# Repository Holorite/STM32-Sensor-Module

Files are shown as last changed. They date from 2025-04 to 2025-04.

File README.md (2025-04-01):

STM32U031C8T6 sensor module for CottonCandy.

**Debugger Digikey Part #**: 497-STLINK-V3MINIE-ND

Possible Improvements:
1. Use STM32L1 for extended preferred on JLCPCB (alternatives may be possible to reduce assembly cost)
2. Change stlink connector (2x7) to 7 (2x1) 1.27mm pitch headeres so they can be assembled by JLC (2x5 pin interface is also possible)
3. SMD stlink connectors are easier to use (but more expensive)
4. Replace CO2 with a more accurate sensor (SCD40, library very likely available), can remove other sensors too.
5. Change order of CC header pins to match 2.0 interface
6. Add LSE for accurate RTC or LPUART functionality
7. Remove some breakout pins and replace with ready I2C + power for sensor connections
8. Modify interface so module can connect vertically to CottonCandy
9. ADC not usable (with 1/3 bridge) when tested using dry ice (-80C?)

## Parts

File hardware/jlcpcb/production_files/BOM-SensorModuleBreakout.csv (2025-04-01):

Comment | Designator | Footprint | LCSC | Quantity
10n | C6 | C_0402_1005Metric | C15195 | 1
100n | C10,C11,C12,C2,C3,C4,C5,C9 | C_0402_1005Metric | C1525 | 8
4.7u | C1 | C_0603_1608Metric | C19666 | 1
STC31-C-R3 | U3 | XDCR_STC31-C-R3 | C22396918 | 1
LED | D1 | LED_0603_1608Metric | C2286 | 1
2M | R4 | R_0603_1608Metric | C22976 | 1
STM32U031C8Tx | U1 | LQFP-48_7x7mm_P0.5mm | C23172783 | 1
220r | R6 | R_0402_1005Metric | C25091 | 1
10k | R1,R2,R3 | R_0402_1005Metric | C25744 | 3
1M | R5 | R_0402_1005Metric | C26083 | 1
1u | C7,C8 | C_0402_1005Metric | C52923 | 2
SHT4x | U2 | Sensirion_DFN-4_1.5x1.5mm_P0.8mm_SHT4x_NoCentralPad | C7461861 | 1
MS5607-02BA | U5 | LGA-8_3x5mm_P1.25mm | C97627 | 1

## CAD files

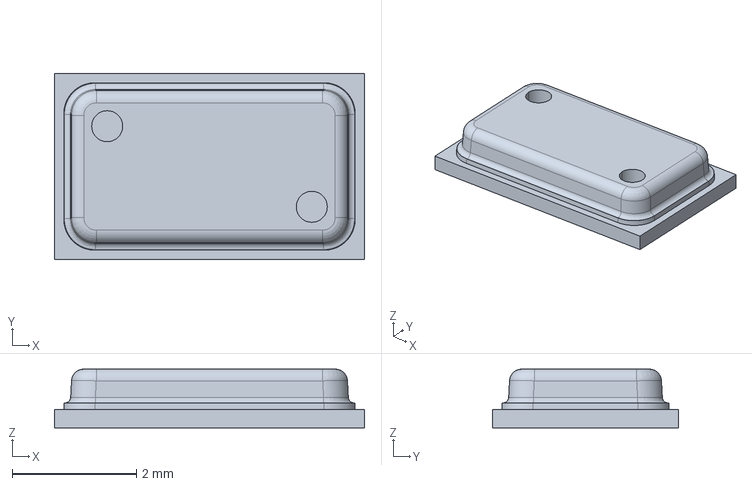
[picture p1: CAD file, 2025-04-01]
hardware/MS560702BA03_50/c-ms560702ba03-50-a-3d.stp
5.00 x 3.00 x 0.95 mm

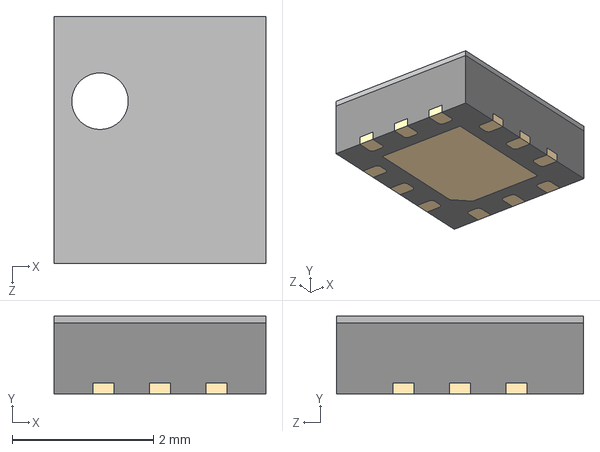
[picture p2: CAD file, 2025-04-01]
hardware/STC31_C_R3/STC31-C-R3.step
3.00 x 1.10 x 3.50 mm

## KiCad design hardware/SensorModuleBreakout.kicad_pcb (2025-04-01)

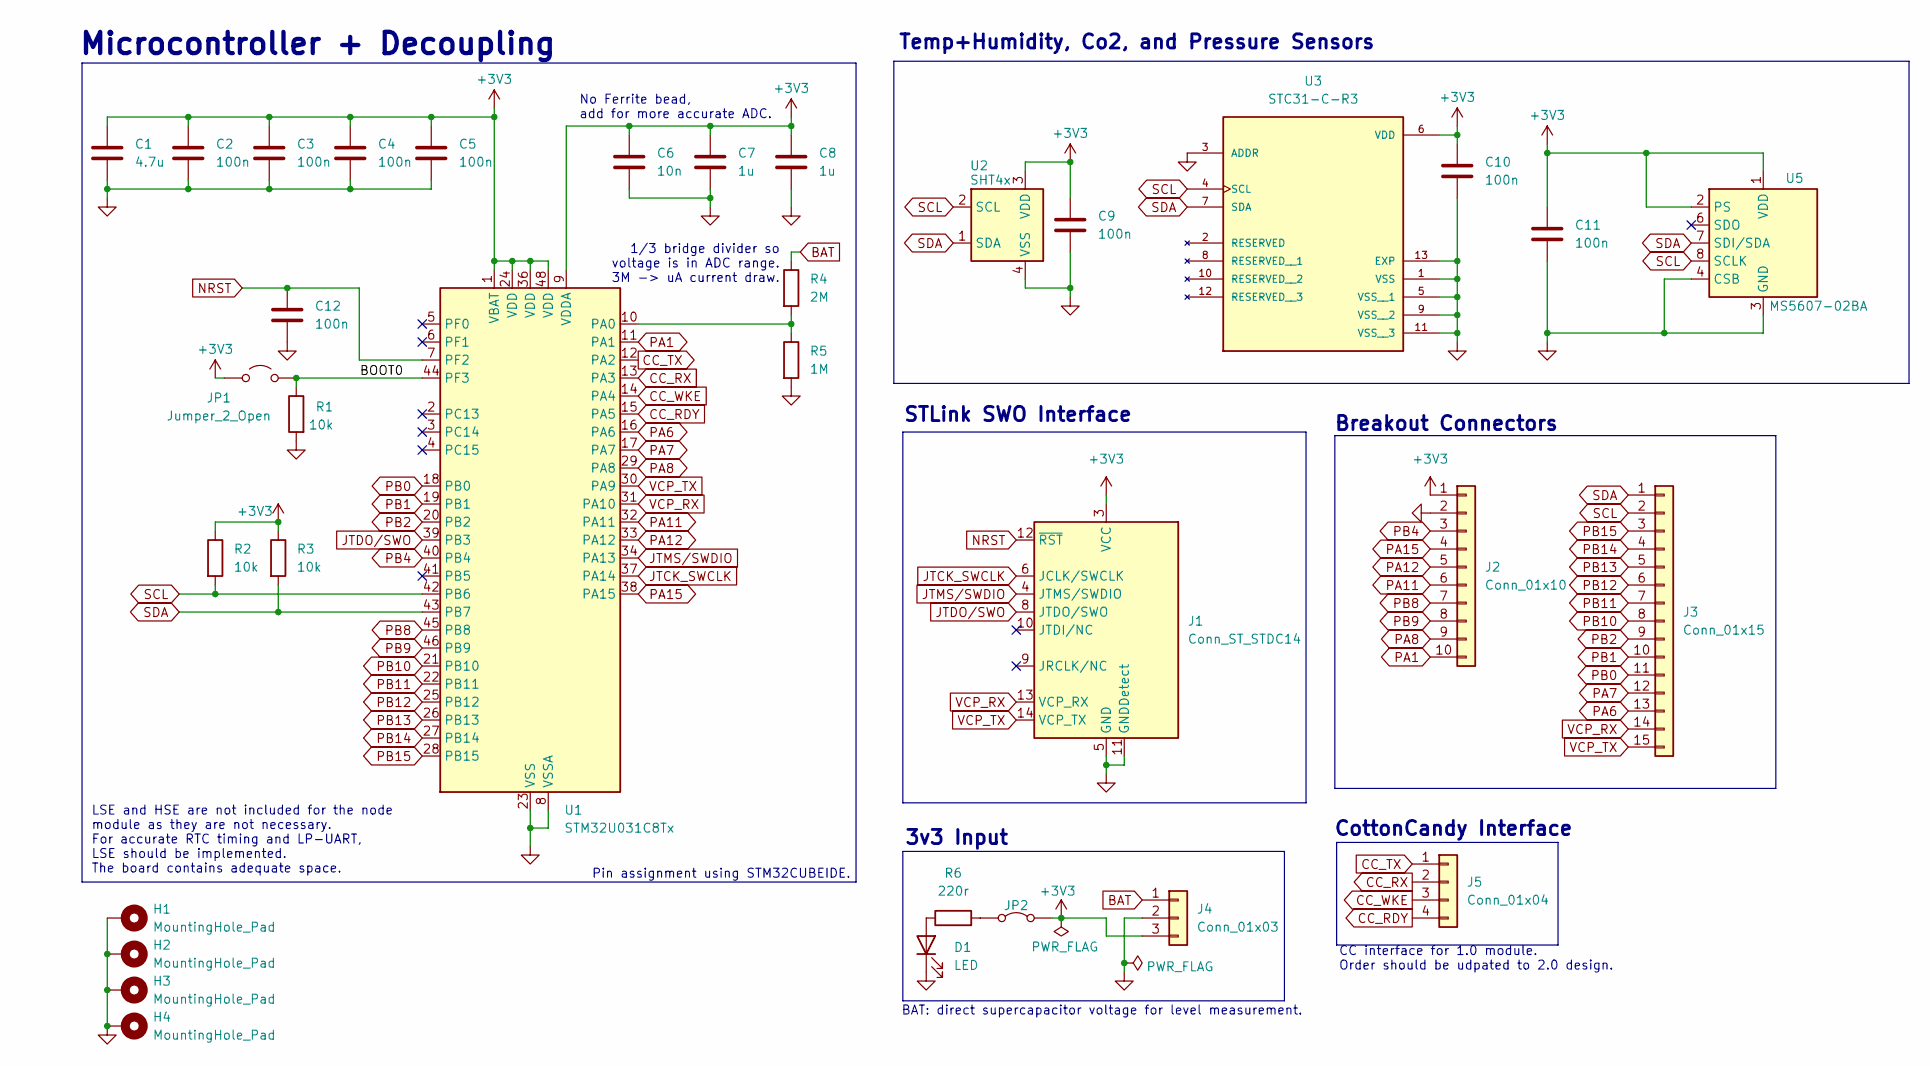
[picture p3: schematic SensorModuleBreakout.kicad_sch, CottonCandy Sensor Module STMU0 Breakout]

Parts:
C1: 4.7u; C_0603_1608Metric
C2, C3, C4, C5, C9, C10, C11, C12: 100n; C_0402_1005Metric
C6: 10n; C_0402_1005Metric
C7, C8: 1u; C_0402_1005Metric
D1: LED; LED_0603_1608Metric
H1, H2, H3, H4: MountingHole_Pad; MountingHole_3.2mm_M3_DIN965_Pad
J1: Conn_ST_STDC14; PinHeader_2x07_P1.27mm_Vertical
J2: Conn_01x10; PinHeader_1x10_P2.54mm_Vertical
J3: Conn_01x15; PinHeader_1x15_P2.54mm_Vertical
J4: Conn_01x03; JST_XH_B3B-XH-A_1x03_P2.50mm_Vertical
J5: Conn_01x04; JST_XH_B4B-XH-A_1x04_P2.50mm_Vertical
JP1: Jumper_2_Open; TestPoint_2Pads_Pitch2.54mm_Drill0.8mm
JP2: JP; TestPoint_2Pads_Pitch2.54mm_Drill0.8mm
R1, R2, R3: 10k; R_0402_1005Metric
R4: 2M; R_0603_1608Metric
R5: 1M; R_0402_1005Metric
R6: 220r; R_0402_1005Metric
U1: STM32U031C8Tx; LQFP-48_7x7mm_P0.5mm
U2: SHT4x; Sensirion_DFN-4_1.5x1.5mm_P0.8mm_SHT4x_NoCentralPad
U3: STC31-C-R3; XDCR_STC31-C-R3; PARTREV 3.2
U5: MS5607-02BA; LGA-8_3x5mm_P1.25mm

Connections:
+3V3: C1.1, C2.1, C3.1, C4.1, C5.1, C6.1, C7.1, C8.1, C9.1, C10.1, C11.1, J1.3 (VCC), J2.1, J4.3, JP1.1 (A), JP2.2 (B), R2.1, R3.1, U1.1 (VBAT), U1.9 (VDDA), U1.24 (VDD), U1.36 (VDD), U1.48 (VDD), U2.3 (VDD), U3.6 (VDD), U5.1 (VDD), U5.2 (PS); also elsewhere on the board
/BOOT0: JP1.2 (B), R1.1, U1.44 (PF3)
CC_RDY: J5.4, U1.15 (PA5)
CC_RX: J5.2, U1.13 (PA3)
CC_TX: J5.1, U1.12 (PA2)
CC_WKE: J5.3, U1.14 (PA4)
GND: C1.2, C2.2, C3.2, C4.2, C5.2, C6.2, C7.2, C8.2, C9.2, C10.2, C11.2, C12.2, D1.1 (K), H1.1, H2.1, H3.1, H4.1, J1.5 (GND), J1.7 (GND), J1.11 (GNDDetect), J2.2, J4.2, R1.2, R5.2, U1.8 (VSSA), U1.23 (VSS), U1.35 (VSS), U1.47 (VSS), U2.4 (VSS), U3.1 (VSS), U3.3 (ADDR), U3.5 (VSS__1), U3.9 (VSS__2), U3.11 (VSS__3), U3.13 (EXP), U5.3 (GND), U5.4 (CSB), U5.5 (CSB); also elsewhere on the board
JTCK_SWCLK: J1.6 (JCLK/SWCLK), U1.37 (PA14); also elsewhere on the board
JTDO/SWO: J1.8 (JTDO/SWO), U1.39 (PB3); also elsewhere on the board
JTMS/SWDIO: J1.4 (JTMS/SWDIO), U1.34 (PA13); also elsewhere on the board
NRST: C12.1, J1.12 (~RST), U1.7 (PF2); also elsewhere on the board
unnamed: D1.2 (A), R6.1
unnamed: JP2.1 (A), R6.2
unnamed: R4.2, R5.1, U1.10 (PA0)
PA1: J2.10, U1.11 (PA1)
PA6: J3.13, U1.16 (PA6)
PA7: J3.12, U1.17 (PA7)
PA8: J2.9, U1.29 (PA8)
PA11: J2.6, U1.32 (PA11)
PA12: J2.5, U1.33 (PA12)
PA15: J2.4, U1.38 (PA15)
PB0: J3.11, U1.18 (PB0)
PB1: J3.10, U1.19 (PB1)
PB2: J3.9, U1.20 (PB2)
PB4: J2.3, U1.40 (PB4)
PB8: J2.7, U1.45 (PB8)
PB9: J2.8, U1.46 (PB9)
PB10: J3.8, U1.21 (PB10)
PB11: J3.7, U1.22 (PB11)
PB12: J3.6, U1.25 (PB12)
PB13: J3.5, U1.26 (PB13)
PB14: J3.4, U1.27 (PB14)
PB15: J3.3, U1.28 (PB15)
SCL: J3.2, R2.2, U1.42 (PB6), U2.2 (SCL), U3.4 (SCL), U5.8 (SCLK)
SDA: J3.1, R3.2, U1.43 (PB7), U2.1 (SDA), U3.7 (SDA), U5.7 (SDI/SDA)
VBAT: J4.1, R4.1
VCP_RX: J1.13 (VCP_RX), J3.14, U1.31 (PA10); also elsewhere on the board
VCP_TX: J1.14 (VCP_TX), J3.15, U1.30 (PA9); also elsewhere on the board

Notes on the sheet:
No Ferrite bead, add for more accurate ADC.
Breakout Connectors
Pin assignment using STM32CUBEIDE.
LSE and HSE are not included for the node module as they are not necessary. For accurate RTC timing and LP-UART, LSE should be implemented. The board contains adequate space.
1/3 bridge divider so voltage is in ADC range. 3M -> uA current draw.
3v3 Input
CottonCandy Interface
STLink SWO Interface
Microcontroller + Decoupling
CC interface for 1.0 module. Order should be udpated to 2.0 design.
BAT: direct supercapacitor voltage for level measurement.
Temp+Humidity, Co2, and Pressure Sensors

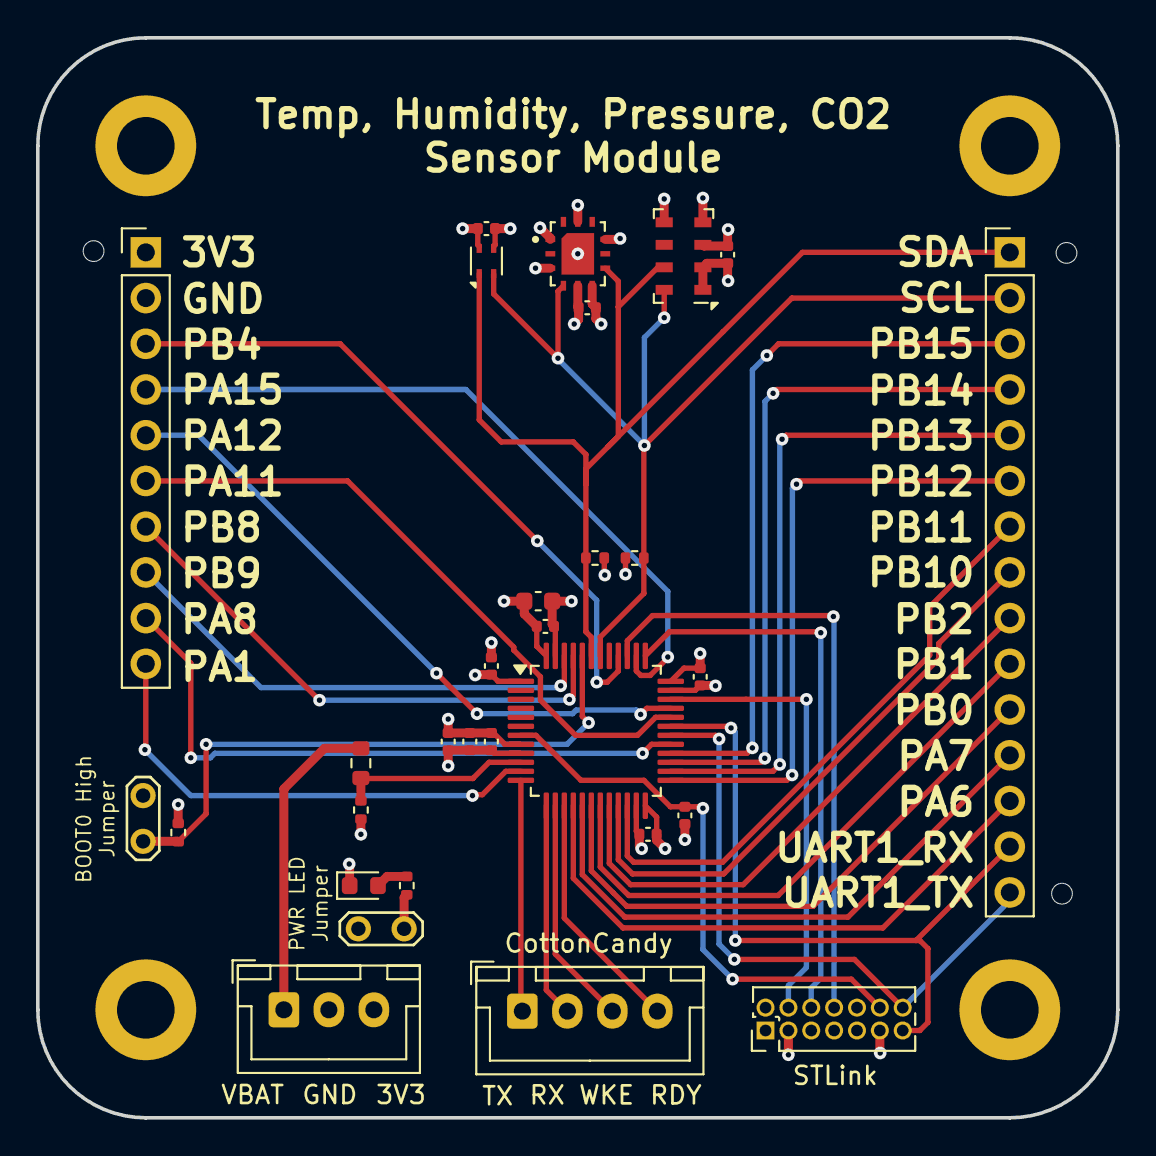
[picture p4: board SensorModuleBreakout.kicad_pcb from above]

Board: 4 copper layers, 60.0 x 60.0 mm, 34 parts (0 on the bottom side), 38 nets.

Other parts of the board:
STLink: Conn_ST_STDC14; PinHeader_2x07_P1.27mm_Vertical

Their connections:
+3V3: STLink.3 (VCC); also elsewhere on the board
GND: STLink.5 (GND), STLink.7 (GND), STLink.11 (GNDDetect); also elsewhere on the board
JTCK_SWCLK: STLink.6 (JCLK/SWCLK); also elsewhere on the board
JTDO/SWO: STLink.8 (JTDO/SWO); also elsewhere on the board
JTMS/SWDIO: STLink.4 (JTMS/SWDIO); also elsewhere on the board
NRST: STLink.12 (~RST); also elsewhere on the board
VCP_RX: STLink.13 (VCP_RX); also elsewhere on the board
VCP_TX: STLink.14 (VCP_TX); also elsewhere on the board

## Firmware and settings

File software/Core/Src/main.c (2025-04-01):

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
/* Includes ------------------------------------------------------------------*/
#include "main.h"

/* USER CODE BEGIN Includes */
#include "stdio.h"

// STC31
#include "stc31/sensirion_common.h"
#include "stc31/sensirion_i2c_hal.h"
#include "stc31/stc3x_i2c.h"
#include <inttypes.h>

#include "stc31/sht4x.h"

#include "stc31/ms5.h"
/* USER CODE END Includes */

/* USER CODE BEGIN PD */

#define STC31 0x29 << 1

/* USER CODE END PD */

ADC_HandleTypeDef hadc1;

I2C_HandleTypeDef hi2c1;

RTC_HandleTypeDef hrtc;

UART_HandleTypeDef huart1;
UART_HandleTypeDef huart2;

void SystemClock_Config(void);
static void MX_GPIO_Init(void);
static void MX_I2C1_Init(void);
static void MX_RTC_Init(void);
static void MX_USART1_UART_Init(void);
static void MX_USART2_UART_Init(void);
static void MX_ADC1_Init(void);
/* USER CODE BEGIN PFP */
#define PUTCHAR_PROTOTYPE int __io_putchar(int ch)
/* USER CODE END PFP */

/* USER CODE BEGIN 0 */

uint8_t rx_buf[12] = {0};
bool data_ready = false;

enum State {
	MEASURE,
	REPORT,
	SLEEP,
	INIT
};

enum State state = INIT;

void HAL_GPIO_EXTI_Rising_Callback(uint16_t GPIO_Pin) {
	if (GPIO_Pin == WKE_Pin) {
		if (state == SLEEP)
			state = MEASURE;
	} else if (GPIO_Pin == RDY_Pin && data_ready) {
		if (state == MEASURE)
			state = REPORT;
	} else {
	  __NOP();
	}
}

void get_battery(uint32_t* bat) {
	HAL_ADCEx_Calibration_Start(&hadc1);
	HAL_ADC_Start(&hadc1);

	HAL_ADC_PollForConversion(&hadc1, 2000);
	uint32_t vref_raw = HAL_ADC_GetValue(&hadc1);

	HAL_ADC_PollForConversion(&hadc1, 2000);
	uint32_t bat_raw = HAL_ADC_GetValue(&hadc1);

	HAL_ADC_Stop(&hadc1);

	//printf("vref raw:\t%ld\r\n", vref_raw);
	//printf("bat raw:\t%ld\r\n", bat_raw);

	////printf("?: %u\r\n", *VREFINT_CAL_ADDR);
	////printf("t: %u\r\n", *((uint16_t*) (0x1FFF6E68UL)));

	uint32_t vref = __HAL_ADC_CALC_VREFANALOG_VOLTAGE(vref_raw, ADC_RESOLUTION_12B);
	//*bat = (int)(__HAL_ADC_CALC_DATA_TO_VOLTAGE(vref, bat_raw, ADC_RESOLUTION_12B)*3.18f);

	// find out the voltage divider ratio, in this case 3.18. and multiply by 1.367. That gives us the coefficient 4.35f.
	double temp = (double)bat_raw / 4095 * vref * 4.3f - 1450;
	*bat = temp < 0 ? 0 : (uint32_t)temp;

	//printf("vref:\t%ld\r\n", vref);
	//printf("bat:\t%ld\r\n", *bat);
}
/* USER CODE END 0 */

/**
  * @brief  The application entry point.
  * @retval int
  */
int main(void)
{

  /* MCU Configuration--------------------------------------------------------*/

  /* Reset of all peripherals, Initializes the Flash interface and the Systick. */
  HAL_Init();

  /* Configure the system clock */
  SystemClock_Config();

  /* Initialize all configured peripherals */
  MX_GPIO_Init();
  MX_I2C1_Init();
  MX_RTC_Init();
  MX_USART1_UART_Init();
  MX_USART2_UART_Init();
  MX_ADC1_Init();
  /* USER CODE BEGIN 2 */
  printf("\r\nSTM32 CO2 Sensor Startup!\r\n");

  stc3x_init(0x29);


  if ((HAL_I2C_IsDeviceReady(&hi2c1, STC31, 2, 1000)) != HAL_OK) {
	  printf("STC31 not ready: %lu\r\n", hi2c1.ErrorCode);
	  HAL_Delay(1000);
  } else {
	  printf("Good!\r\n");
  }

  if ((HAL_I2C_IsDeviceReady(&hi2c1, 0x77 << 1, 2, 1000)) != HAL_OK) {
  	  printf("ms5 not ready: %lu\r\n", hi2c1.ErrorCode);
  	  HAL_Delay(1000);
    } else {
  	  //printf("Good!\r\n");
    }


  int16_t error = 0;
//  error = stc3x_prepare_product_identifier();
//  if (error) {
//	  printf("Error executing stc3x_prepare_product_identifier(): %i\r\n", error);
//  }

//  uint32_t product_number;
//  uint64_t serial_number = 0;
//  error = stc3x_get_product_id(&product_number, &serial_number);
//  if (error) {
//	  printf("Error executing stc3x_read_product_identifier(): %i\r\n", error);
//  } else {
//	  printf("Product Number: 0x%08lx\r\n", product_number);
//	  printf("Serial Number: %" PRIu64 "\r\n", serial_number);
//  }

  stc3x_test_result_t self_test_output;
  error = stc3x_self_test(&self_test_output);
  if (error) {
	  printf("Error executing stc3x_self_test(): %i\n", error);
  } else {
	  //printf("Self Test: 0x%04x (OK = 0x0000)\n", self_test_output.value);
  }

  error = stc3x_set_binary_gas(0x0003);
  if (error) {
	  printf("Error executing stc3x_set_binary_gas(): %i\n", error);
  } else {
	  //printf("Set binary gas to 0x0003\n");
  }

  if (sht4x_probe() != STATUS_OK) {
	  printf("SHT sensor probing failed\r\n");
  }
  //printf("SHT sensor probing successful\r\n");

  uint16_t gas_ticks;
  uint16_t temperature_ticks;

  float gas;
  float temperature;


  struct sht_data_t sht_data;

  struct ms5_data_t ms5_data;

  uint32_t bat;

  uint8_t raw_data[8];


  /* USER CODE END 2 */

  /* Infinite loop */
  /* USER CODE BEGIN WHILE */
  while (1)
  {
    /* USER CODE END WHILE */

    /* USER CODE BEGIN 3 */

	  data_ready = false;

	  stc3x_enter_sleep_mode();
//	  printf("Processing packet from 0C: 80-1-3-69-9F-68-4C-A3-34-87-5D\r\n");
	  //printf("Going to sleep zzzz\r\n\r\n");
	  state = SLEEP;
	  while (state == SLEEP) {
		HAL_SuspendTick();
		//HAL_RTCEx_SetWakeUpTimer_IT(&hrtc, 0x2805, RTC_WAKEUPCLOCK_RTCCLK_DIV16, 0);
		HAL_PWR_EnterSTOPMode(PWR_LOWPOWERREGULATOR_ON, PWR_STOPENTRY_WFI);
	  }

	  SystemClock_Config();
	  HAL_ResumeTick();

	  //printf("Woke up!\r\n");

	  int8_t ret = sht4x_measure_blocking_read(&sht_data);
	  if (ret == STATUS_OK) {
		  //printf("measured temperature: %ld.%ld degreeCelsius, "measured humidity: %ld.%ld percentRH\n", sht_data.temp/1000, sht_data.temp/10%10, sht_data.rh/1000, sht_data.rh/10%10);
		  sensirion_common_uint16_t_to_bytes(sht_data.temp_raw, raw_data);
		  sensirion_common_uint16_t_to_bytes(sht_data.rh_raw, &raw_data[2]);

		  //printf("Raw temp: %d, rh: %d\r\n", sht_data.temp_raw, sht_data.rh_raw);
	  } else {
		  printf("error reading measurement\n");
	  }

//	  error = ms5_measure_data(&ms5_data);
//	  if (error) {
//		  //printf("Error getting MS5 Pressure: %i\r\n", error);
//	  } else {
//		  //printf("Pressure: %ld\r\n", ms5_data.pressure);
//	  }

	  stc3x_exit_sleep_mode();
	  HAL_Delay(12);
	  error = stc3x_set_binary_gas(0x0003);
	  if (error) {
		  printf("Error executing stc3x_set_binary_gas(): %i\n", error);
	  }
	  HAL_Delay(12);

	  error = stc3x_set_relative_humidity_raw(sht_data.rh_raw);
	  if (error) {
		  printf("Error setting humidity %i\r\n", error);
	  }

	  error = stc3x_set_temperature_raw(sht_data.temp / 5);
	  if (error) {
		  printf("Error setting temp %i\r\n", error);
	  }

	  HAL_Delay(12);

	  error = stc3x_measure_gas_concentration_raw(&gas_ticks, &temperature_ticks);
	  if (error) {
		  printf("Error executing stc3x_measure_gas_concentration_raw(): %i\n", error);
	  } else {
		  gas = 25 * ((float)gas_ticks - 16384.0) / 32768.0;
		  temperature = (float)temperature_ticks / 200.0;
		  sensirion_common_uint16_t_to_bytes(gas_ticks, &raw_data[4]);
		  //printf("raw gas: %d\r\n", gas_ticks);
		  //printf("stc raw temp: %d\r\n", temperature_ticks);
//		  printf("Gas: %d.%d - Temperature: %d.%d\r\n", (int)gas, (int)(gas*100) % 100, (int)temperature, (int)(temperature*100)%100);
	  }

	  get_battery(&bat);
	  sensirion_common_uint16_t_to_bytes((uint16_t)bat, &raw_data[6]);


	  //printf("Data collected, waiting for RQ signal\r\n");
	  data_ready = true;
	  while (state != REPORT) {
		HAL_Delay(25);
	  }

	  const uint8_t packet_size = 8;
	  HAL_UART_Transmit(&huart2, &packet_size, 1, 1000);
	  //printf("Sent packet size\r\n");
	  HAL_Delay(50);

	  //printf("Transmitting Data to CC\r\n");
	  HAL_UART_Transmit(&huart2, (uint8_t*)raw_data, packet_size, 1000);
  }
  /* USER CODE END 3 */
}

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
/* USER CODE BEGIN 4 */
/**
  * @brief  Retargets the C library printf function to the USART.
  *   None
  * @retval None
  */
PUTCHAR_PROTOTYPE
{
  /* Place your implementation of fputc here */
  /* e.g. write a character to the USART1 and Loop until the end of transmission */
  HAL_UART_Transmit(&huart1, (uint8_t *)&ch, 1, 0xFFFF);

  return ch;
}
/* USER CODE END 4 */
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


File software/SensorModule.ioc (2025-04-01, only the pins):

Mcu.UserName=STM32U031C8Tx
PA0.Signal=ADC1_IN4
PA10.Signal=USART1_RX
PA2.Signal=USART2_TX
PA3.Signal=USART2_RX
PA4.GPIO_Label=WKE
PA4.Signal=GPXTI4
PA5.GPIO_Label=RDY
PA5.Signal=GPXTI5
PA9.Signal=USART1_TX
PB3.Signal=DEBUG_JTDO-SWO
PB6.Signal=I2C1_SCL
PB7.Signal=I2C1_SDA

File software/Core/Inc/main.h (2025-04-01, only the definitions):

#define WKE_Pin GPIO_PIN_4
#define WKE_GPIO_Port GPIOA
#define WKE_EXTI_IRQn EXTI4_15_IRQn
#define RDY_Pin GPIO_PIN_5
#define RDY_GPIO_Port GPIOA
#define RDY_EXTI_IRQn EXTI4_15_IRQn

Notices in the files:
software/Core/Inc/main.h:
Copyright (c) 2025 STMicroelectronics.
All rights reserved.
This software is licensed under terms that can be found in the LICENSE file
